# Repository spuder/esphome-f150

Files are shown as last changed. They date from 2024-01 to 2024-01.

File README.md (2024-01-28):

# F150 Remote Start

## Problem

The range of the remote start on a 2014 F150 is abysmal. I often have to walk outside my house just to get the remote start to work. (Even with a fresh battery in the keyfob)

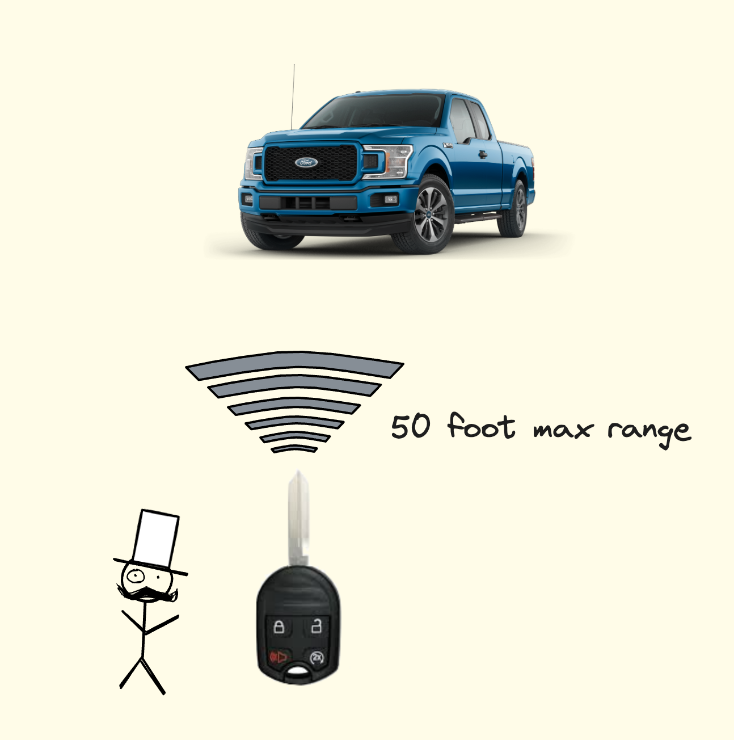
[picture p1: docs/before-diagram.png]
before


## Solution

Using a spare keyfob and a wemos D1 Mini microcontroller, create a semi-permenant remote start beacon that can be stationed near my truck, that can start my truck from my phone/home-assistant. 

The box is placed anywhere that is within range of wifi and the vehicle. 

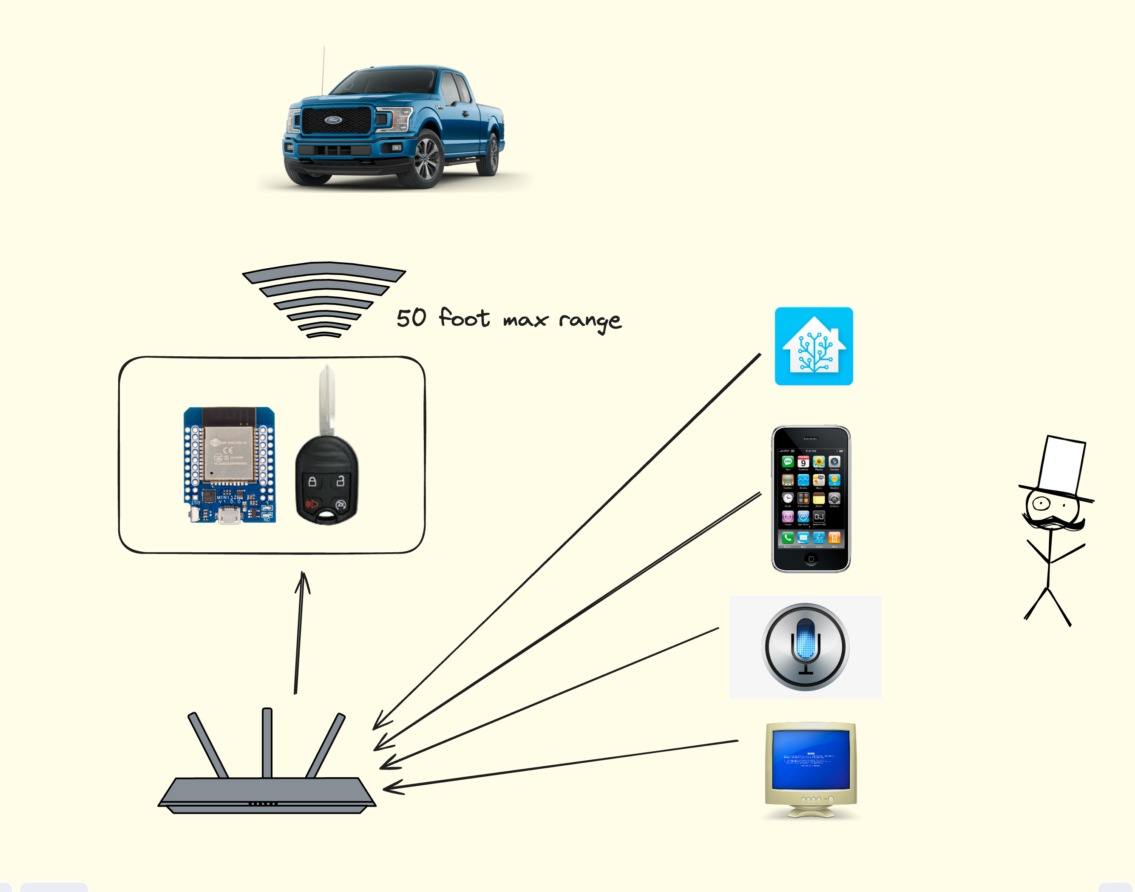
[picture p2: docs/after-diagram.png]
after


Youtube Video Explination:  
Watch the video (https://youtu.be/l3snjHc5gsU)

**Warning** : Never start a vehicle inside an enclosed space (such as a garage), the CO2 buildup is deadly. Only remotely start a vehile that is outdoors. 

## Hardware

- [Additional Key Fobs](https://www.amazon.com/gp/product/B06XS3351F/ref=ewc_pr_img_2?smid=A5K9LFXZIQJ2T&th=1)
- [PCBs (optional)](https://www.amazon.com/ELEGOO-Prototype-Soldering-Compatible-Arduino/dp/B072Z7Y19F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)
- [Wimos D1 mini ESP8266](https://www.amazon.com/Aceirmc-ESP8266-Internet-Development-Compatible/dp/B07V84VWSM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)
- [Any 5V WS2812x Led strip or led](https://www.amazon.com/ALITOVE-100pcs-WS2812B-Addressable-Arduino/dp/B01D1FFVOA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)

Video on programming [f150 keyfobs](https://www.youtube.com/watch?v=c2BaSCcAnhg).

## Schematic

My particular keyfob has buttons that pull signal low (gnd) when pressed.

|GPIO| Pin|
| --- | --- |
| D5 | Lock |
| D6 | Unlock |
| D7 | Start |
| 2 | Status LED | 
| D3 | RGB Led | 

My particular truck has the following sequence to do a remote start
1. Press lock button 
2. Press remote start button twice
3. (Truck will start)
4. Press unlock button to enter truck

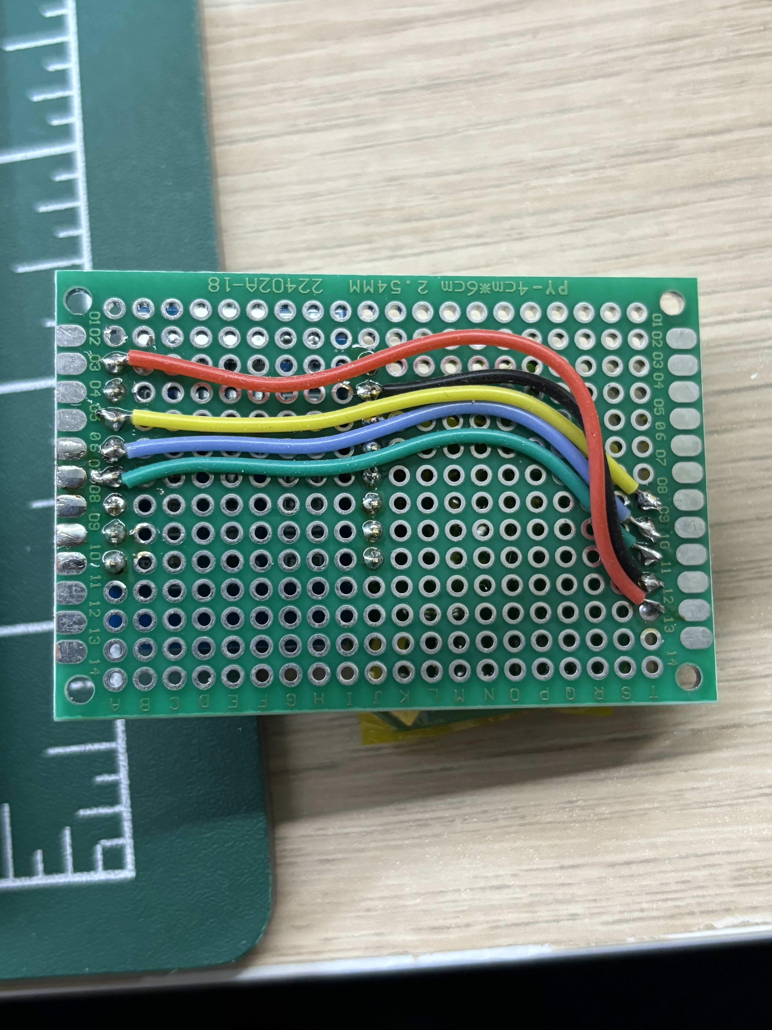
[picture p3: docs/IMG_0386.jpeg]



## 3d Printing

STL and 3MF files are included in the [3d prints](./3d%20prints/) folder. 

A pre-sliced multi color print for bambu x1c is provided. 

Printed with PETG

| Color | AMS slot | 
|--- | --- |
| black | 1 |
| clear | 3 |
| blue | 4 | 

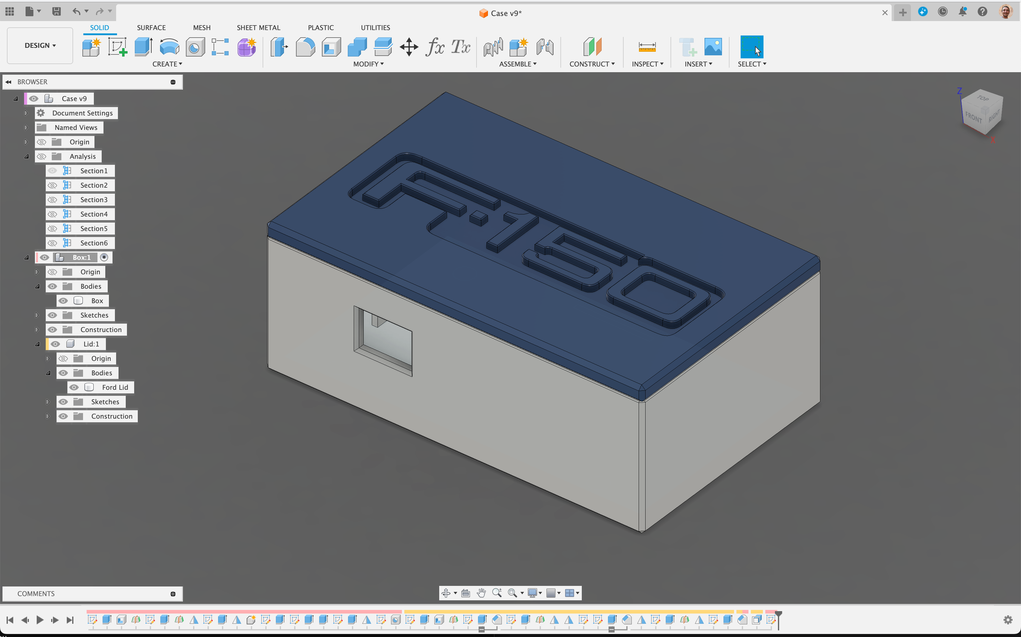
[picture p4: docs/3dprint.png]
  
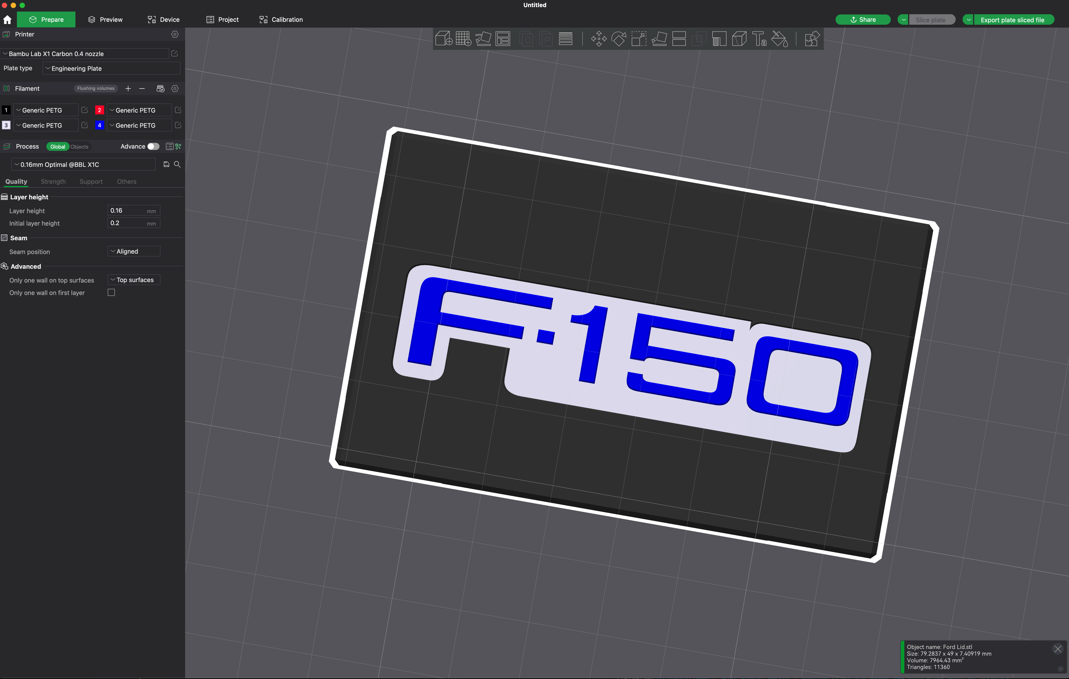
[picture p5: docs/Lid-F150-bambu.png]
  

## Leds

The lid is printed with transparent PETG fillament to show the internal Led status. 

```
Lock = Red
Unlock = Green
Start = Rainbow Animation
Stop = Blue
```

The LEDs will light up for 10 minutes (the max amount of time an F150 remote start will idle for), then return to white. 

## HomeAssistant

If you have the 'esphome' addon installed in HomeAssistant, the device will show up automatically. 
Once the device is added, it will show up on your dashboard. 

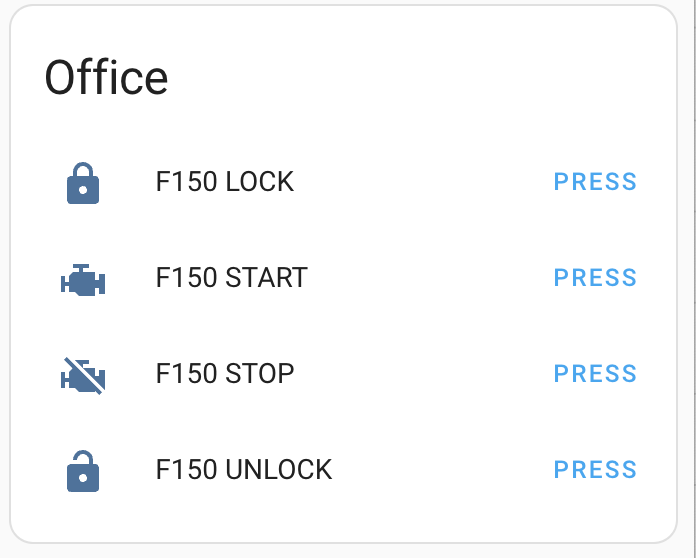
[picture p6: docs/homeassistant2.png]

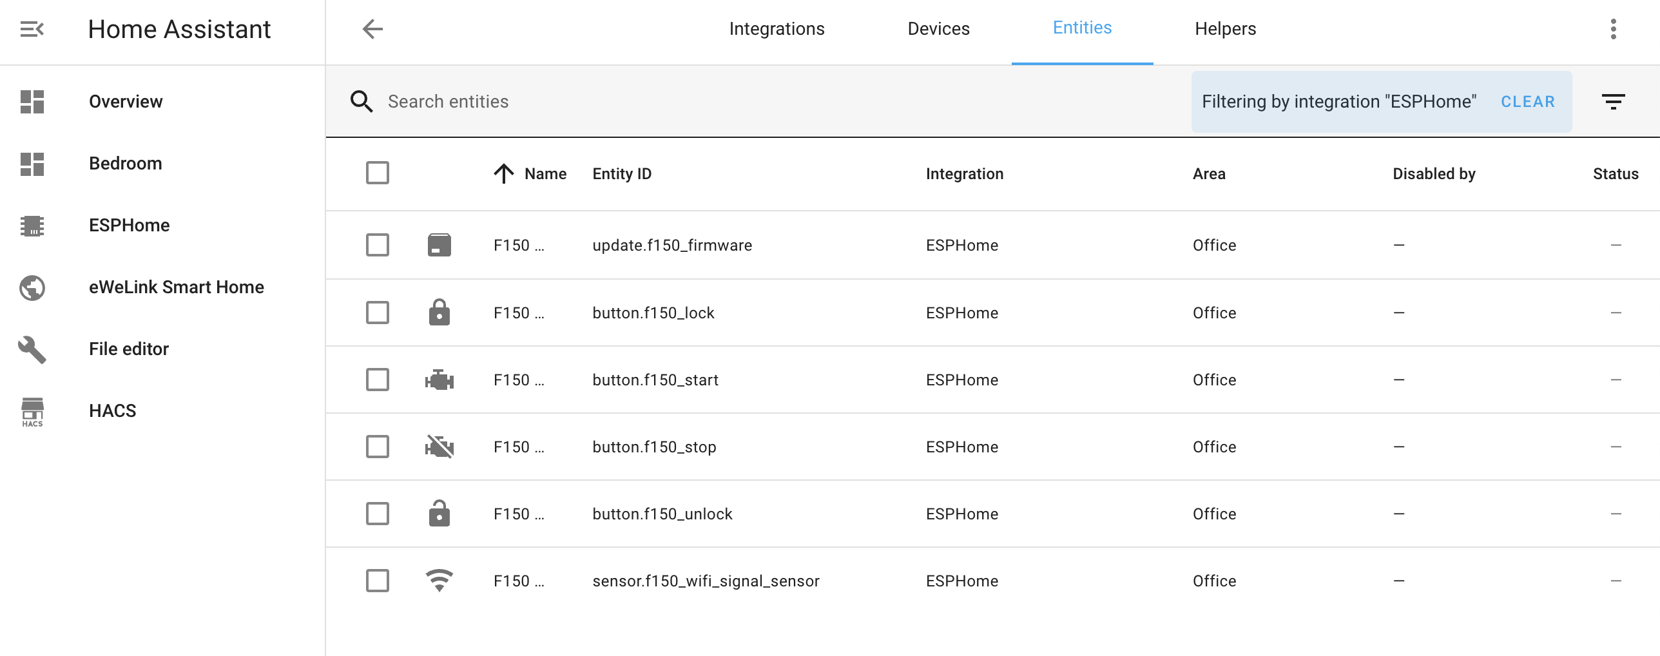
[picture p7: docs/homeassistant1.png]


## Development

Assuming you are using `direnv`, setup an `.envrc` file with environment variables to load. 

```
ls /dev/cu*   #note the address of the usb device
echo 'export USB_ADDRESS=/dev/cu.usbserial-xxxx' > .envrc
```

Make a `secrets.yaml` file

```bash
touch conf.d/secrets.yaml
```

Then add the following variables:
```yaml
wifi_ssid: "foobar"
wifi_password: "correct-horse-battery-staple"
web_username: "admin"
web_password: "correct-horse-battery-staple"
```

Then compile and upload the firmware

If you are running debug mode, it will join your wifi automatically. 
If you have debug mode disabled, it will create a new Wifi HotSpot. You can join the hotspot and join it to your wifi using your phone. 

`make run-ota`

Then navigate to [http://f150.local](http://f150.local) on the network

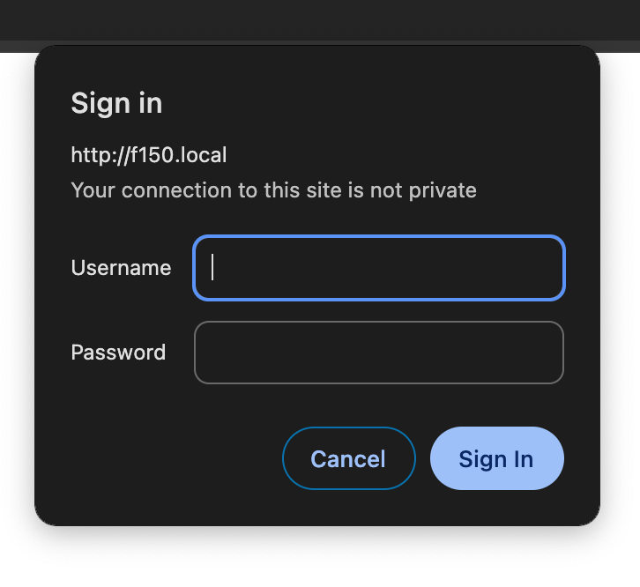
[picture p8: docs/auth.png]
  
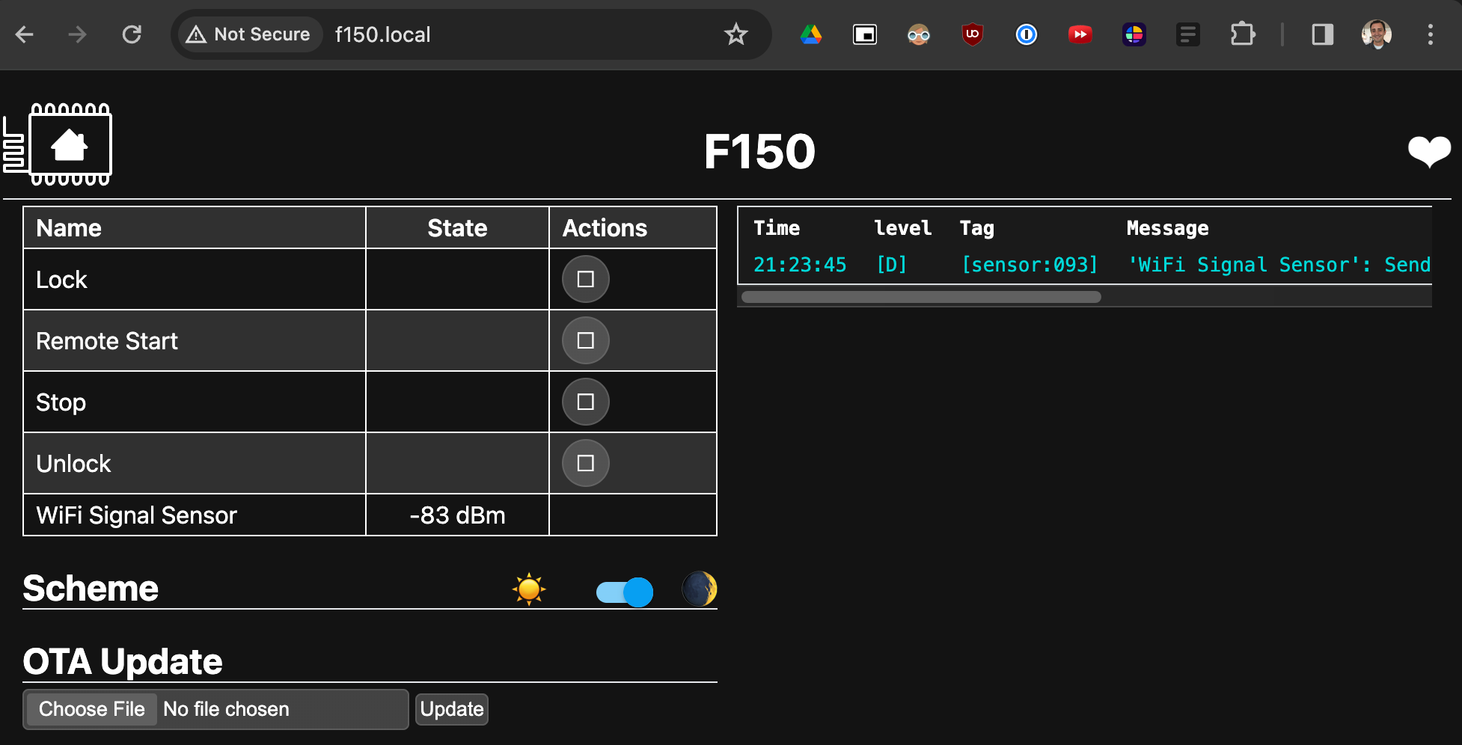
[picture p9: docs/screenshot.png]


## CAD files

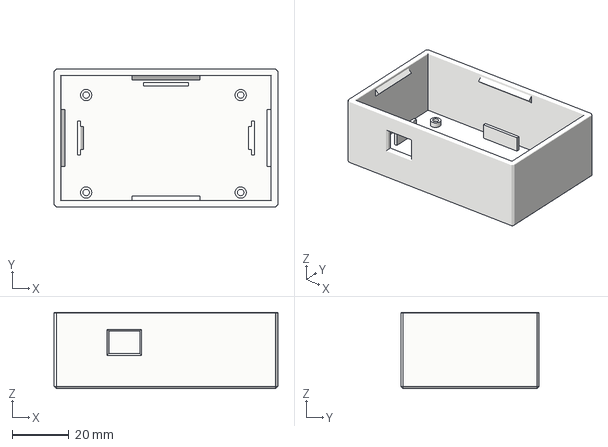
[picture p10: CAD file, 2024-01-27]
3d prints/Box.3mf
79.3 x 49.0 x 27.0 mm

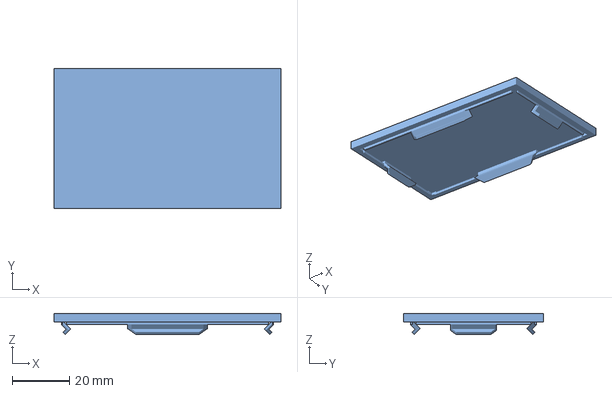
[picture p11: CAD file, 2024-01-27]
3d prints/Lid-Blank.3mf
79.3 x 49.0 x 7.41 mm

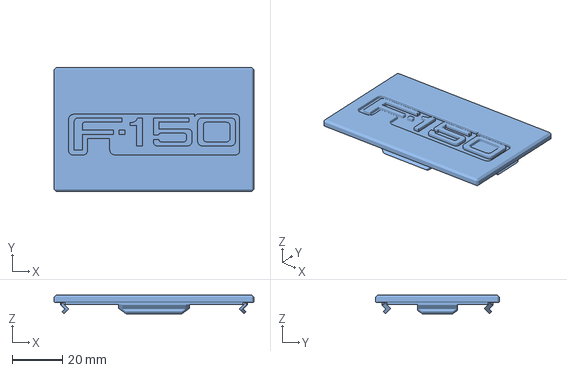
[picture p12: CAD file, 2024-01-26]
3d prints/Lid-F150.3mf
79.3 x 49.0 x 7.41 mm

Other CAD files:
3d prints/F150-Lid-bambu-x1c-PETG-0.4mm.3mf
3d prints/Box.stl
3d prints/Case v9.f3d
3d prints/Lid-F150.stl

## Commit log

2024-01-27 Add case
    [Case v7.f3d, Lid-Blank.3mf]
2024-01-27 Update box
    [Box.3mf, Box.stl, Case v7.f3d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]
2024-01-29 leds 6
